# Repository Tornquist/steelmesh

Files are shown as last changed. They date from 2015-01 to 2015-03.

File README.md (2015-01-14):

# Steelmesh
(Twitch Plays ECE477 -- Collaborative Robot Project)

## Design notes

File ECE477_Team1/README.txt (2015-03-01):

1)  Install Eagle
2)  Add the Sparkfun libraries (https://learn.sparkfun.com/tutorials/how-to-install-and-setup-eagle/using-the-sparkfun-libraries)
3)  Copy the microchip.lbr file into your lbr directory (it will overwrite the current microchip library).
3.1)  Also copy the Johanson_antenna.lbr and crw.lbr files
4)  You probably have to add the project folder to the "Projects" directory list (kinda like the libraries).
5)  Open the schematic/board and look at it and stuff.
6)  ????????????
7)  Profit.

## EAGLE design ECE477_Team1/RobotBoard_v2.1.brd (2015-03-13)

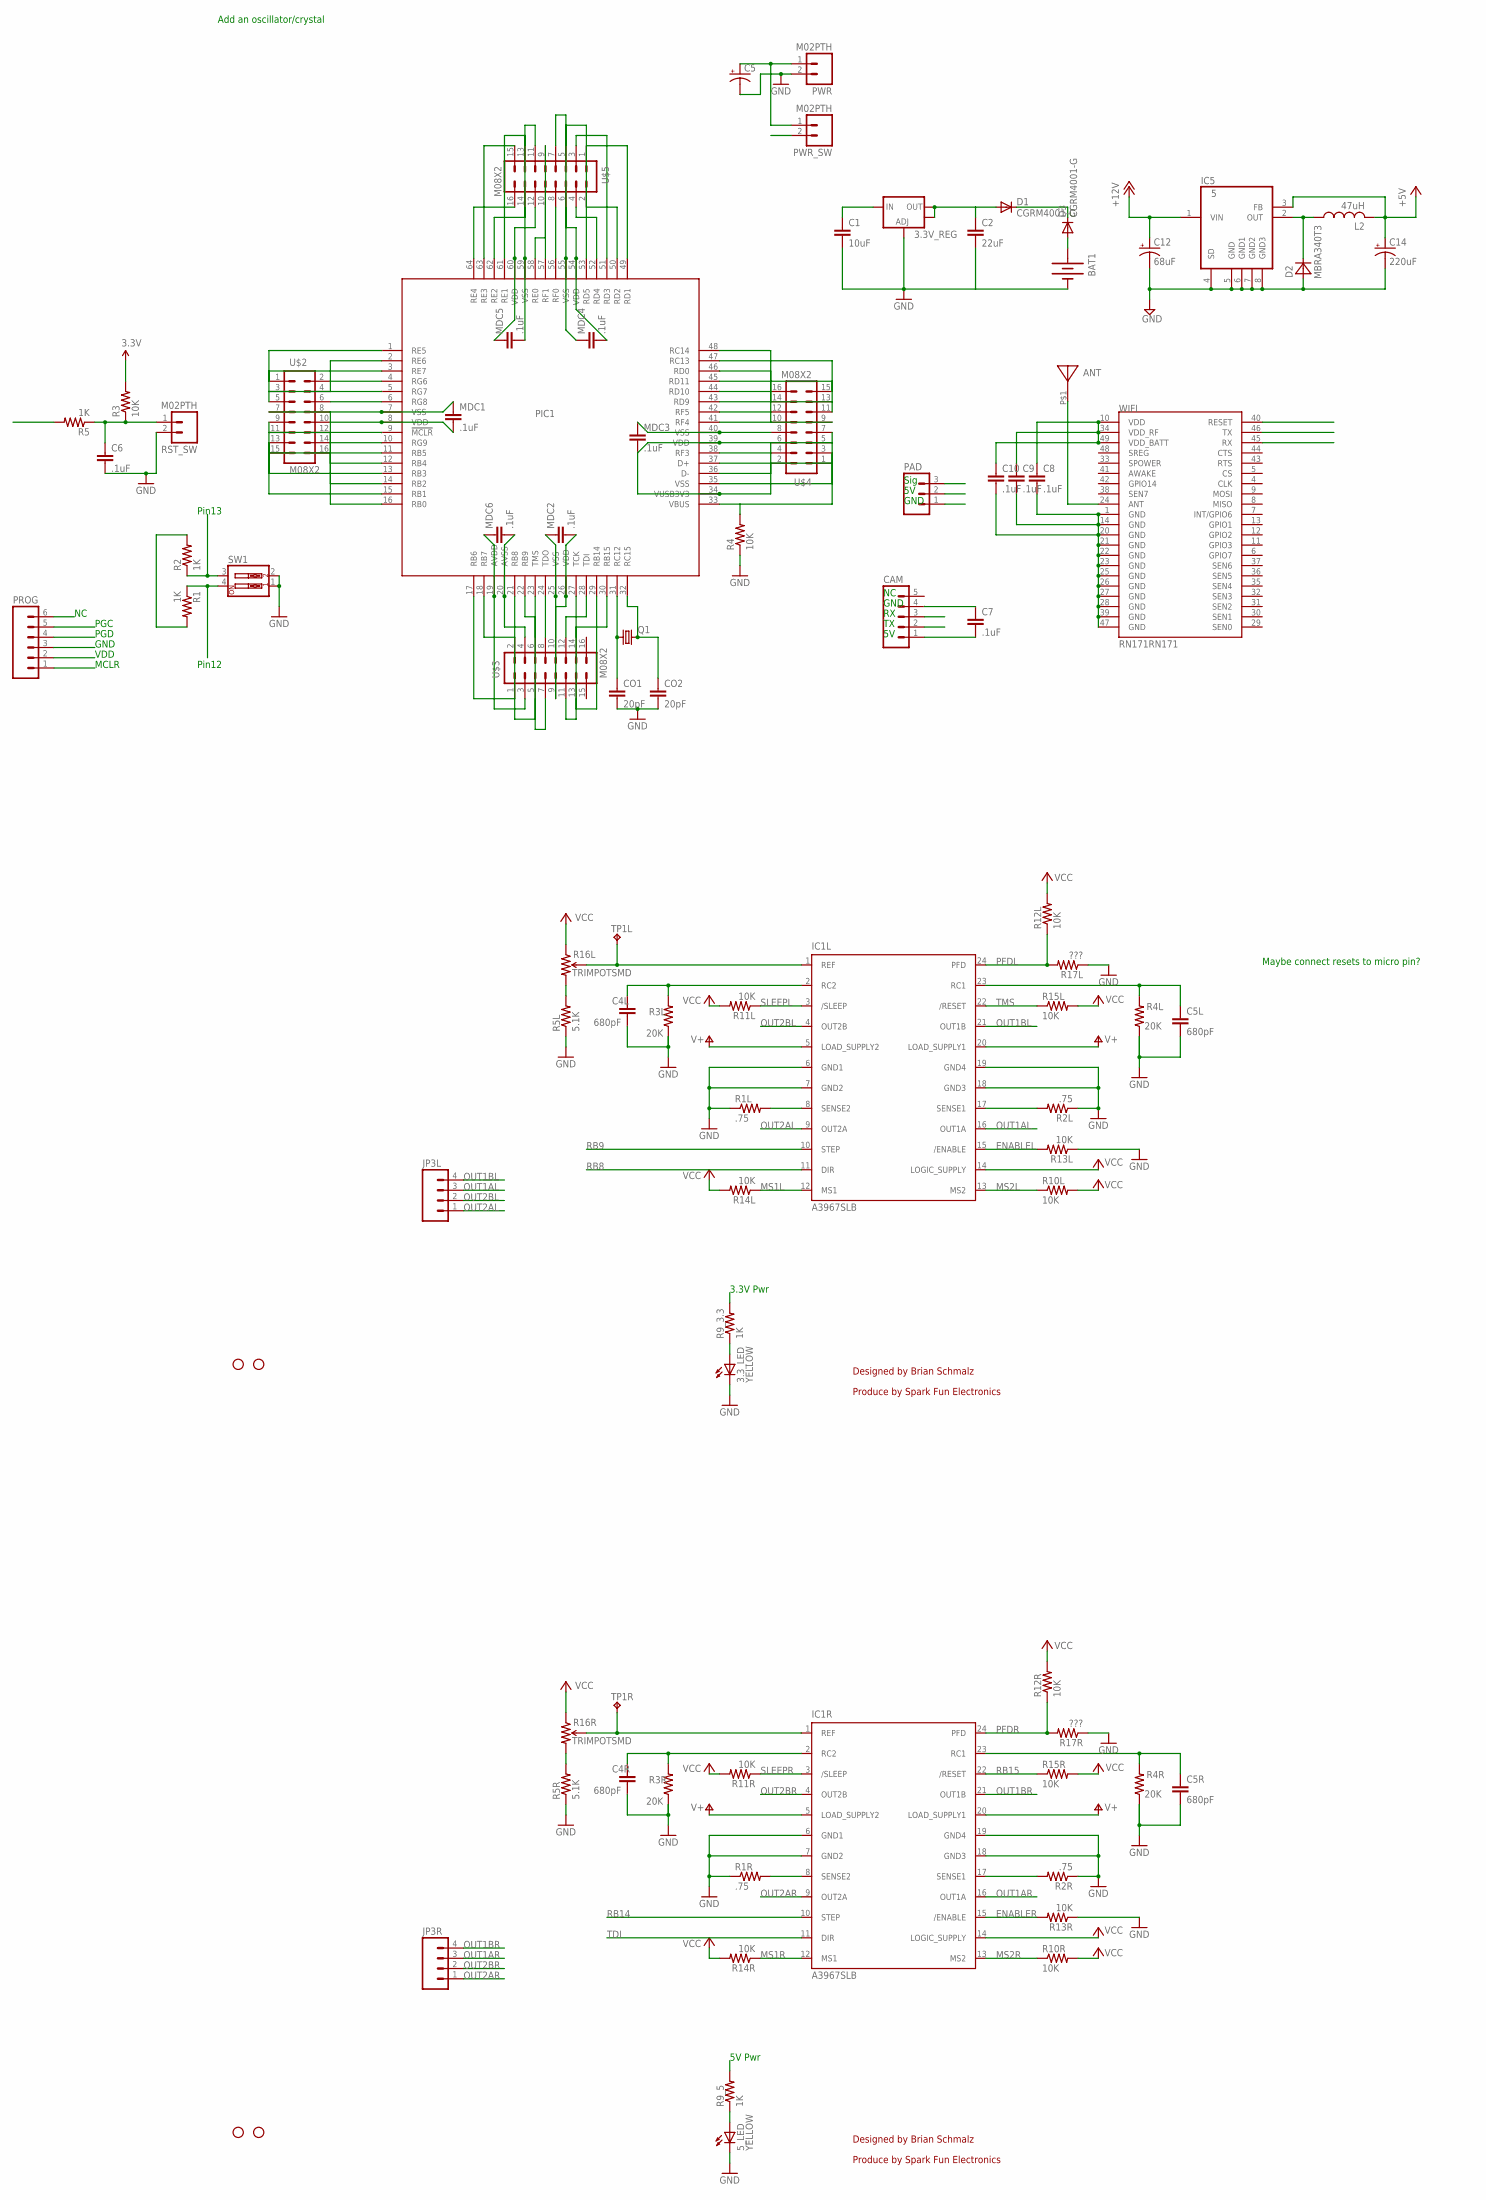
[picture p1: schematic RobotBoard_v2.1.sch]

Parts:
3.3V_REG: V_REG_LM1117SOT223; SOT223
3.3_LED, 5_LED: YELLOW; LED-0603
ANT: 2450AT18A100
BAT1: BATTERY20PTH; BATTCOM_20MM_PTH
C1: 10uF; 0603
C2: 22uF; 0603
C4L, C4R, C5L, C5R: 680pF; C0402
C5: CAP_POLPTH4; CPOL-RADIAL-1000UF-25V
C6, C7, C8, C9, C10: .1uF; 0603
C12: 68uF; PANASONIC_D
C14: 220uF; PANASONIC_D
CAM: M05LOCK; 1X05_LOCK
CO1, CO2: 20pF; 0603
D1, D3: CGRM4001-G; SOD-123_MINI-SMA
D2: MBRA340T3; SMA
IC1L, IC1R: A3967SLB; SO24W
IC5: 5; SO08
JP1, JP2, JP8, JP9: STAND-OFF
JP3L, JP3R: M041X04_NO_SILK; 1X04_NO_SILK
L2: 47uH; 6000-XXXX-RC
MDC1, MDC2, MDC3, MDC4, MDC5, MDC6: .1uF; 0603
PAD: M03POLAR; MOLEX-1X3
PIC1: PIC32MZ2048ECM064; TQFP64-10X10X1MM
PROG: M06LOCK; 1X06_LOCK
PWR: M02PTH; 1X02
PWR_SW: M02PTH; 1X02
Q1: CRYSTALHC49UP; HC49UP
R1, R2, R5, R9_3.3, R9_5: 1K; C0402
R1L, R1R, R2L, R2R: .75; R0805
R3, R4, R10L, R10R, R11L, R11R, R12L, R12R, R13L, R13R, R14L, R14R, R15L, R15R: 10K; C0402
R3L, R3R, R4L, R4R: 20K; C0402
R5L, R5R: 5.1K; C0402
R16L, R16R: TRIMPOTSMD; TRIMPOT-3MM
R17L, R17R: ???; C0402
RST_SW: M02PTH; 1X02
SW1: SW_DIP-2; DIPSWITCH-02
TP1L, TP1R: TPPAD1-13; P1-13
U$2, U$3, U$4, U$5: M08X2; 2X8
WIFI: RN171RN171; RN171

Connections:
3.3V: C8.1, C9.1, C10.1, D1.C, D3.C, IC1L.14 (LOGIC_SUPPLY), IC1R.14 (LOGIC_SUPPLY), MDC1.2, MDC2.2, MDC3.2, MDC4.2, MDC5.1, MDC6.1, PIC1.8 (VDD), PIC1.19 (AVDD), PIC1.26 (VDD), PIC1.34 (VUSB3V3), PIC1.39 (VDD), PIC1.54 (VDD), PIC1.60 (VDD), PROG.2, R1.2, R2.2, R3.2, R9_3.3.2, R10L.2, R10R.2, R11L.2, R11R.2, R12L.2, R12R.2, R14L.2, R14R.2, R15L.2, R15R.2, R16L.1 (CCW), R16R.1 (CCW), U$2.8, U$3.3, U$3.10, U$4.2, U$4.7, U$5.6, U$5.12, WIFI.10 (VDD), WIFI.34 (VDD_RF), WIFI.49 (VDD_BATT)
5V: 3.3V_REG.3 (IN), C1.1, C7.2, C14.+, CAM.1, IC5.3 (FB), L2.2, PAD.2, R9_5.2
12V: C12.+, IC1L.5 (LOAD_SUPPLY2), IC1L.20 (LOAD_SUPPLY1), IC1R.5 (LOAD_SUPPLY2), IC1R.20 (LOAD_SUPPLY1), IC5.1 (VIN), PWR_SW.2
!MCLR: PIC1.9 (!MCLR), PROG.1, R5.2, U$2.9
A44: C6.1, R3.1, R5.1, RST_SW.1
D+: PIC1.37 (D+), U$4.5
D-: PIC1.36 (D-), U$4.4
ENABLEL: IC1L.15 (/ENABLE), R13L.2
ENABLER: IC1R.15 (/ENABLE), R13R.2
GND: 3.3V_REG.1 (ADJ), 3.3_LED.C, 5_LED.C, BAT1.2 (-), C1.2, C2.2, C4L.2, C4R.2, C5.2 (-), C5L.2, C5R.2, C6.2, C7.1, C8.2, C9.2, C10.2, C12.-, C14.-, CAM.4, CO1.2, CO2.2, D2.A, IC1L.6 (GND1), IC1L.7 (GND2), IC1L.18 (GND3), IC1L.19 (GND4), IC1R.6 (GND1), IC1R.7 (GND2), IC1R.18 (GND3), IC1R.19 (GND4), IC5.4 (SD), IC5.5 (GND), IC5.6 (GND1), IC5.7 (GND2), IC5.8 (GND3), MDC1.1, MDC2.1, MDC3.1, MDC4.1, MDC5.2, MDC6.2, PAD.1, PIC1.7 (VSS), PIC1.20 (AVSS), PIC1.25 (VSS), PIC1.35 (VSS), PIC1.40 (VSS), PIC1.55 (VSS), PIC1.59 (VSS), PROG.3, PWR.2, R1L.1, R1R.1, R2L.1, R2R.1, R3L.1, R3R.1, R4.1, R4L.1, R4R.1, R5L.1, R5R.1, R13L.1, R13R.1, R17L.1, R17R.1, RST_SW.2, SW1.1, SW1.2, U$2.7, U$3.4, U$3.9, U$4.3, U$4.8, U$5.7, U$5.11, WIFI.1 (GND), WIFI.14 (GND), WIFI.20 (GND), WIFI.21 (GND), WIFI.22 (GND), WIFI.23 (GND), WIFI.25 (GND), WIFI.26 (GND), WIFI.27 (GND), WIFI.28 (GND), WIFI.39 (GND), WIFI.47 (GND)
MS1L: IC1L.12 (MS1), R14L.1
MS1R: IC1R.12 (MS1), R14R.1
MS2L: IC1L.13 (MS2), R10L.1
MS2R: IC1R.13 (MS2), R10R.1
unnamed: IC1L.8 (SENSE2), R1L.2
unnamed: 3.3_LED.A, R9_3.3.1
unnamed: IC1L.17 (SENSE1), R2L.2
unnamed: BAT1.1 (+), D3.A
unnamed: C4L.1, IC1L.2 (RC2), R3L.2
unnamed: CO1.1, PIC1.31 (RC12), Q1.1
unnamed: C5L.1, IC1L.23 (RC1), R4L.2
unnamed: IC1R.8 (SENSE2), R1R.2
unnamed: IC1R.17 (SENSE1), R2R.2
unnamed: C4R.1, IC1R.2 (RC2), R3R.2
unnamed: R5L.2, R16L.3 (CW)
unnamed: IC1L.1 (REF), R16L.2 (WIPER), TP1L.1
unnamed: C5R.1, IC1R.23 (RC1), R4R.2
unnamed: IC1R.1 (REF), R16R.2 (WIPER), TP1R.1
unnamed: CO2.1, PIC1.32 (RC15), Q1.2
unnamed: R5R.2, R16R.3 (CW)
unnamed: 5_LED.A, R9_5.1
unnamed: ANT.P$1, WIFI.24 (ANT)
unnamed: C5.1 (+), PWR.1, PWR_SW.1
unnamed: D2.C, IC5.2 (OUT), L2.1
OUT1AL: IC1L.16 (OUT1A), JP3L.3
OUT1AR: IC1R.16 (OUT1A), JP3R.3
OUT1BL: IC1L.21 (OUT1B), JP3L.4
OUT1BR: IC1R.21 (OUT1B), JP3R.4
OUT2AL: IC1L.9 (OUT2A), JP3L.1
OUT2AR: IC1R.9 (OUT2A), JP3R.1
OUT2BL: IC1L.4 (OUT2B), JP3L.2
OUT2BR: IC1R.4 (OUT2B), JP3R.2
PFDL: IC1L.24 (PFD), R12L.1, R17L.2
PFDR: IC1R.24 (PFD), R12R.1, R17R.2
RB0: PIC1.16 (RB0), PROG.4, U$2.16
RB1: PIC1.15 (RB1), PROG.5, U$2.15
RB2: PIC1.14 (RB2), U$2.14
RB3: PIC1.13 (RB3), R2.1, SW1.3, U$2.13
RB4: PIC1.12 (RB4), R1.1, SW1.4, U$2.12
RB5: PIC1.11 (RB5), U$2.11
RB6: PIC1.17 (RB6), U$3.1
RB7: PIC1.18 (RB7), U$3.2
RB8: IC1L.11 (DIR), PIC1.21 (RB8), U$3.5
RB9: IC1L.10 (STEP), PIC1.22 (RB9), U$3.6
RB14: IC1R.10 (STEP), PIC1.29 (RB14), U$3.13
RB15: IC1R.22 (/RESET), PIC1.30 (RB15), R15R.1, U$3.14
RC13: PIC1.47 (RC13), U$4.15
RC14: PIC1.48 (RC14), U$4.16
RD0: CAM.3, PIC1.46 (RD0), U$4.14
RD1: PIC1.49 (RD1), U$5.1
RD2: PIC1.50 (RD2), U$5.2
RD3: PIC1.51 (RD3), U$5.3
RD4: PIC1.52 (RD4), U$5.4
RD5: PIC1.53 (RD5), U$5.5
RD9: CAM.2, PIC1.43 (RD9), U$4.11
RD10: PIC1.44 (RD10), U$4.12
RD11: PIC1.45 (RD11), U$4.13
RE0: PIC1.58 (RE0), U$5.10
RE1: PIC1.61 (RE1), U$5.13
RE2: PIC1.62 (RE2), U$5.14
RE3: PIC1.63 (RE3), U$5.15
RE4: PIC1.64 (RE4), U$5.16
RE5: PIC1.1 (RE5), U$2.1
RE6: PIC1.2 (RE6), U$2.2
RE7: PIC1.3 (RE7), U$2.3
RF0: PIC1.56 (RF0), U$5.8
RF1: PIC1.57 (RF1), U$5.9
RF3: PAD.3, PIC1.38 (RF3), U$4.6
RF4: PIC1.41 (RF4), U$4.9
RF5: PIC1.42 (RF5), U$4.10
RG6: PIC1.4 (RG6), U$2.4, WIFI.40 (RESET)
RG7: PIC1.5 (RG7), U$2.5, WIFI.45 (RX)
RG8: PIC1.6 (RG8), U$2.6, WIFI.46 (TX)
RG9: PIC1.10 (RG9), U$2.10
SKSDJIOJ: 3.3V_REG.2 (OUT), 3.3V_REG.4 (OUT), C2.1, D1.A
SLEEPL: IC1L.3 (/SLEEP), R11L.1
SLEEPR: IC1R.3 (/SLEEP), R11R.1
TCK: PIC1.27 (TCK), U$3.11
TDD: PIC1.24 (TDO), U$3.8
TDI: IC1R.11 (DIR), PIC1.28 (TDI), U$3.12
TMS: IC1L.22 (/RESET), PIC1.23 (TMS), R15L.1, U$3.7
VBUS: PIC1.33 (VBUS), R4.2, U$4.1

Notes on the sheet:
Designed by Brian Schmalz
Produce by Spark Fun Electronics
Add an oscillator/crystal
GND
Sig
Maybe connect resets to micro pin?
5V Pwr
3.3V Pwr
MCLR
VDD
PGD
PGC
Pin12
Pin13

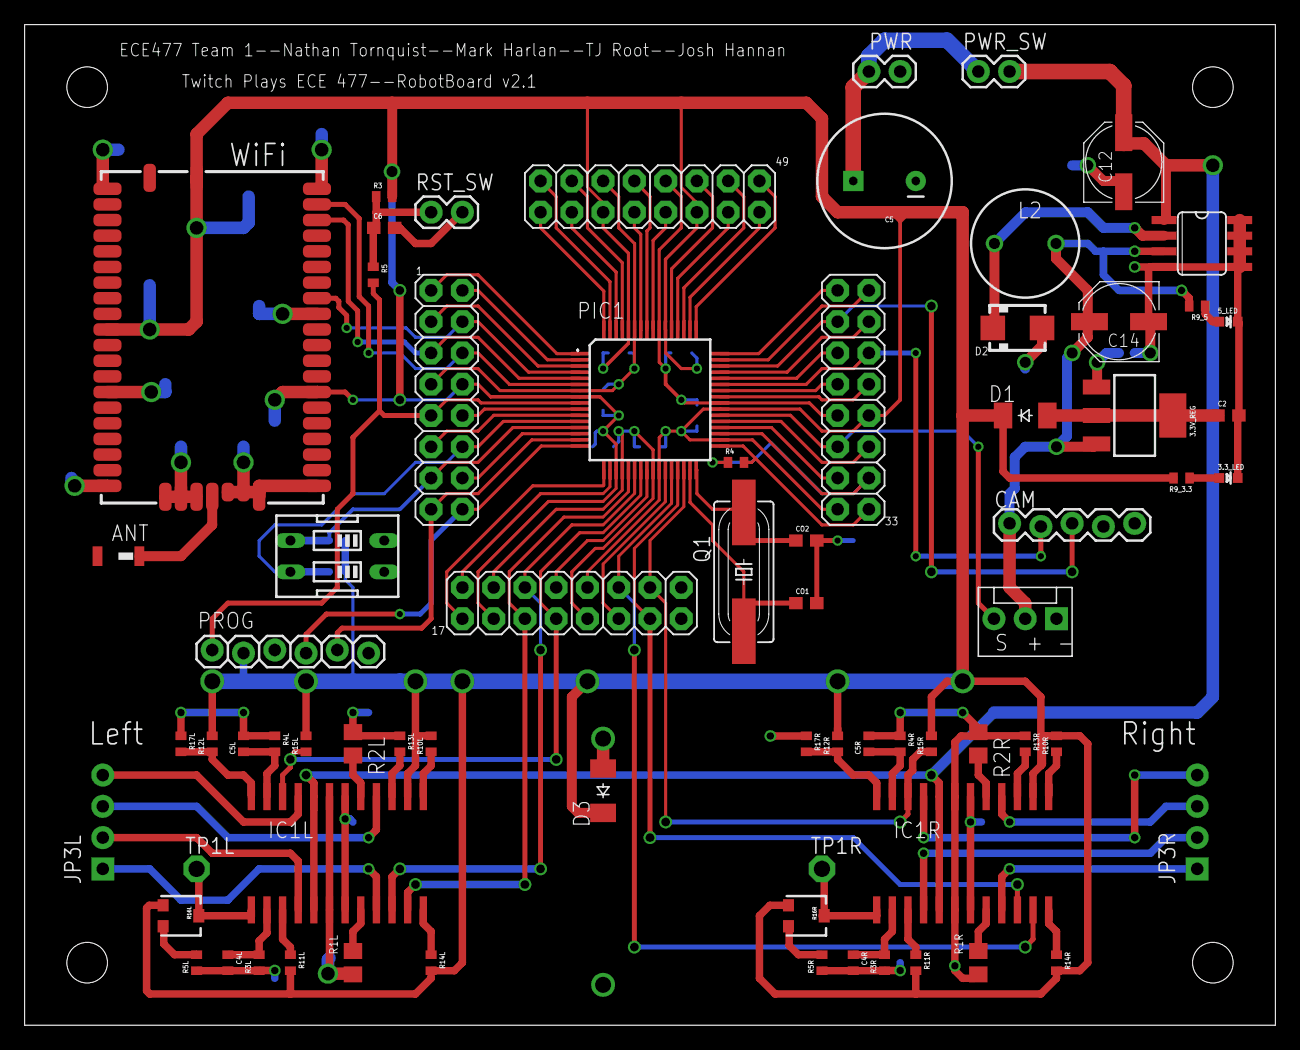
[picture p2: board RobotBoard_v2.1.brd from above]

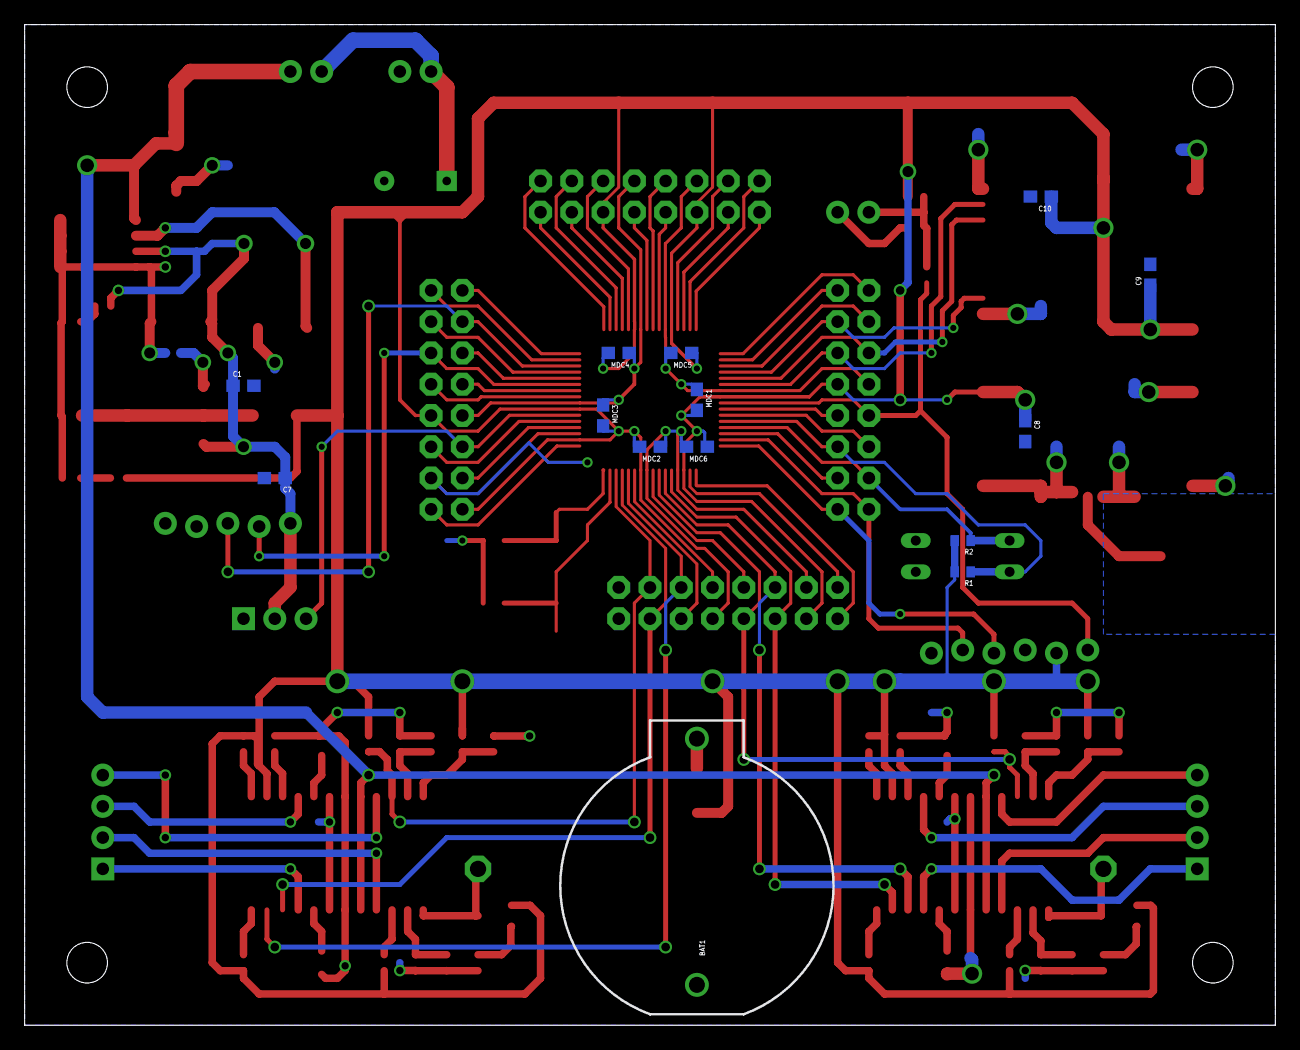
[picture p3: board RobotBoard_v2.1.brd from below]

Board: 2 copper layers, 101.6 x 81.3 mm, 89 parts (14 on the bottom side), 92 nets.

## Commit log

2015-02-27 Initial commit of PCB files (v1.0)
    [RobotBoard.brd, RobotBoard.sch, RobotBoard_v1.0.brd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]
2015-02-27 Added Antenna
    [RobotBoard.brd, RobotBoard.sch, RobotBoard_v1.0.brd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]
2015-03-01 Updated Power Regulators and created v2.0
    [RobotBoard_v1.1.brd, RobotBoard_v1.1.sch, RobotBoard_v2.0.brd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]
2015-03-11 Added Version 2.1
    [RobotBoard_v2.1.brd, RobotBoard_v2.1.sch]
2015-03-13 Added Battery
    [RobotBoard_v2.1.brd, RobotBoard_v2.1.sch]

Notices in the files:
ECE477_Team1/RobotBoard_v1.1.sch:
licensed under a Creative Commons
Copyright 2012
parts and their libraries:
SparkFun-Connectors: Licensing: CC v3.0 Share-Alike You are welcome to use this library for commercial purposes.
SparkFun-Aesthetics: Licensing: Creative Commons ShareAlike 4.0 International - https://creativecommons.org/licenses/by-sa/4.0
